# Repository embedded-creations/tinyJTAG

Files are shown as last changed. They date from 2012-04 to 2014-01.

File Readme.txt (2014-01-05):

tinyJTAG is a modification of the USBasp project to program via JTAG
instead of SPI or TPI, and to run on the ATtiny85.  

LICENSE
tinyJTAG is distributed under the terms and conditions of the GNU GPL version
2 (see "firmware/usbdrv/License.txt" for details).

CAUTIONS

Hardware:
All 6 IO pins of the ATtiny85 are used, including the reset pin.  The 
RSTDISBL fuse needs to be programmed to disable external reset funcionality
and enable use of the reset pin as IO.  After programming the fuse the part
can only be programmed through a high-voltage programmmer, or through the 
USBaspLoader-tiny85 boot loader.  The project is intended to be used in
conjunction with the USBaspLoader-tiny85 boot loader, and so doesn't include
an easy way to disable the external reset fuse in the makefile.  The 
USBaspLoader-tiny85 boot loader should be loaded on to the part first, tested
to make sure it was flashed properly, then the reset fuse can be disabled and 
the tinyJTAG firmware loaded through AVRDUDE.

Use:
If loading the the precompiled binary with bootloader, the bootloader will identify itself as a USBasp
programmer with an ATtiny85 target for five seconds before starting the 
tinyJTAG programmer, which will identify itself as a USBasp programmer.  
Wait for five seconds after connecting the tinyJTAG programmer to USB before
using AVRDUDE to connect to the JTAG target.  Be especially cautious when programming
ATtiny85 targets that you are connected to the tinyJTAG application and 
not the bootloader, as you could inadvertently erase the tinyJTAG application.

USE PRECOMPILED VERSION
Firmware:
Set the fuses and load USBaspLoader-tiny85 onto the tiny85 using your programmer of choice
- "make fuses" and "make flash" in USBaspLoader-tiny85\firmware directory
Verify that the boot loader was loaded correctly and that AVRDUDE can connect to it
- a signature read in AVRDUDE should show the ATtiny85 fuses
When you're sure you're ready, disable the external reset fuse on the tiny85
- see "CAUTIONS" in the USBaspLoader-tiny85 project
- "make disablereset" in USBaspLoader-tiny85\firmware directory
Load the tinyJTAG firmware
- "make flash" in tinyJTAG/firmware directory

There are no jumpers that need to be set for programming with an external programmer

BUILDING AND INSTALLING FROM SOURCE CODE

Firmware:
...

For more information on the tinyJTAG programmer, please visit the
following URL:

http://www.embedded-creations.com

(c) 2012 Louis Beaudoin

Below is the unmodified README file for USBasp:

=========================================================================

This is the README file for USBasp.

USBasp is a USB in-circuit programmer for Atmel AVR controllers. It simply
consists of an ATMega88 or an ATMega8 and a couple of passive components.
The programmer uses a firmware-only USB driver, no special USB controller
is needed.

Features:
- Works under multiple platforms. Linux, Mac OS X and Windows are tested.
- No special controllers or smd components are needed.
- Programming speed is up to 5kBytes/sec.
- SCK option to support targets with low clock speed (< 1,5MHz).
- Planned: serial interface to target (e.g. for debugging).

LICENSE

USBasp is distributed under the terms and conditions of the GNU GPL version
2 (see "firmware/usbdrv/License.txt" for details).

USBasp is built with V-USB driver by OBJECTIVE DEVELOPMENT GmbH. See
"firmware/usbdrv/" for further information.

LIMITATIONS

Hardware:
This package includes a circuit diagram. This circuit can only be used for
programming 5V target systems. For other systems a level converter is needed.

Firmware:
The firmware dosn't support USB Suspend Mode. A bidirectional serial
interface to slave exists in hardware but the firmware doesn't support it yet.

USE PRECOMPILED VERSION

Firmware:
Flash "bin/firmware/usbasp.atmega88.xxxx-xx-xx.hex" or
"bin/firmware/usbasp.atmega8.xxxx-xx-xx.hex" to the used controller with a
working programmer (e.g. with avrdude, uisp, ...). Set jumper J2 to activate
USBasp firmware update function.
You have to change the fuse bits for external crystal (see "make fuses").
# TARGET=atmega8    HFUSE=0xc9  LFUSE=0xef
# TARGET=atmega48   HFUSE=0xdd  LFUSE=0xff
# TARGET=atmega88   HFUSE=0xdd  LFUSE=0xff

Windows:
Start Windows and connect USBasp to the system. When Windows asks for a
driver, choose "bin/win-driver". On Win2k and WinXP systems, Windows will
warn that the driver is is not 'digitally signed'. Ignore this message and
continue with the installation.
Now you can run avrdude. Examples:
1. Enter terminal mode with an AT90S2313 connected to the programmer:
   avrdude -c usbasp -p at90s2313 -t
2. Write main.hex to the flash of an ATmega8:
   avrdude -c usbasp -p atmega8 -U flash:w:main.hex

Setting jumpers:
J1 Power target
   Supply target with 5V (USB voltage). Be careful with this option, the
   circuit isn't protected against short circuit!
J2 Jumper for firmware upgrade (not self-upgradable)
   Set this jumper for flashing the ATMega(4)8 of USBasp with another working
   programmer.
J3 SCK option
   If the target clock is lower than 1,5 MHz, you have to set this jumper.
   Then SCK is scaled down from 375 kHz to about 8 kHz.

BUILDING AND INSTALLING FROM SOURCE CODE

Firmware:
To compile the firmware
1. install the GNU toolchain for AVR microcontrollers (avr-gcc, avr-libc),
2. change directory to firmware/
3. run "make main.hex"
4. flash "main.hex" to the ATMega(4)8. E.g. with uisp or avrdude (check
the Makefile option "make flash"). To flash the firmware you have
to set jumper J2 and connect USBasp to a working programmer.
You have to change the fuse bits for external crystal, (check the Makefile
option "make fuses").

Software (avrdude):
AVRDUDE supports USBasp since version 5.2. 
1. install libusb: http://libusb.sourceforge.net/
2. get latest avrdude release: http://download.savannah.gnu.org/releases/avrdude/
3. cd avrdude-X.X.X
5. configure to your environment:
   ./bootstrap (I had to comment out the two if-blocks which verify the
                installed versions of autoconf and automake)
   ./configure
6. compile and install it:
   make 
   make install

Notes on Windows (Cygwin):
Download libusb-win32-device-bin-x.x.x.x.tar.gz from
http://libusb-win32.sourceforge.net/ and unpack it.
-> copy lib/gcc/libusb.a to lib-path
-> copy include/usb.h to include-path
cd avrdude
./configure LDFLAGS="-static" --enable-versioned-doc=no
make

Notes on Darwin/MacOS X:
after "./configure" I had to edit Makefile:
change "avrdude_CPPFLAGS" to "AM_CPPFLAGS"
(why is this needed only on mac? bug in configure.ac?)

Notes on Linux:
To use USBasp as non-root, you have to define some device rules. See
bin/linux-nonroot for an example.

FILES IN THE DISTRIBUTION

Readme.txt ...................... The file you are currently reading
firmware ........................ Source code of the controller firmware
firmware/usbdrv ................. AVR USB driver by Objective Development
firmware/usbdrv/License.txt ..... Public license for AVR USB driver and USBasp
circuit ......................... Circuit diagram in PDF and EAGLE format
bin ............................. Precompiled programs
bin/win-driver .................. Windows driver
bin/firmware .................... Precompiled firmware
bin/linux-nonroot ............... Linux device rule file

MORE INFORMATION

For more information on USBasp and it's components please visit the
following URLs:

USBasp .......................... http://www.fischl.de/usbasp/

Firmware-only V-USB driver ...... http://www.obdev.at/products/vusb/
avrdude ......................... http://www.nongnu.org/avrdude/
libusb .......................... http://libusb.sourceforge.net/
libusb-win32 .................... http://libusb-win32.sourceforge.net/

2011-05-28 Thomas Fischl <tfischl@gmx.de>
http://www.fischl.de

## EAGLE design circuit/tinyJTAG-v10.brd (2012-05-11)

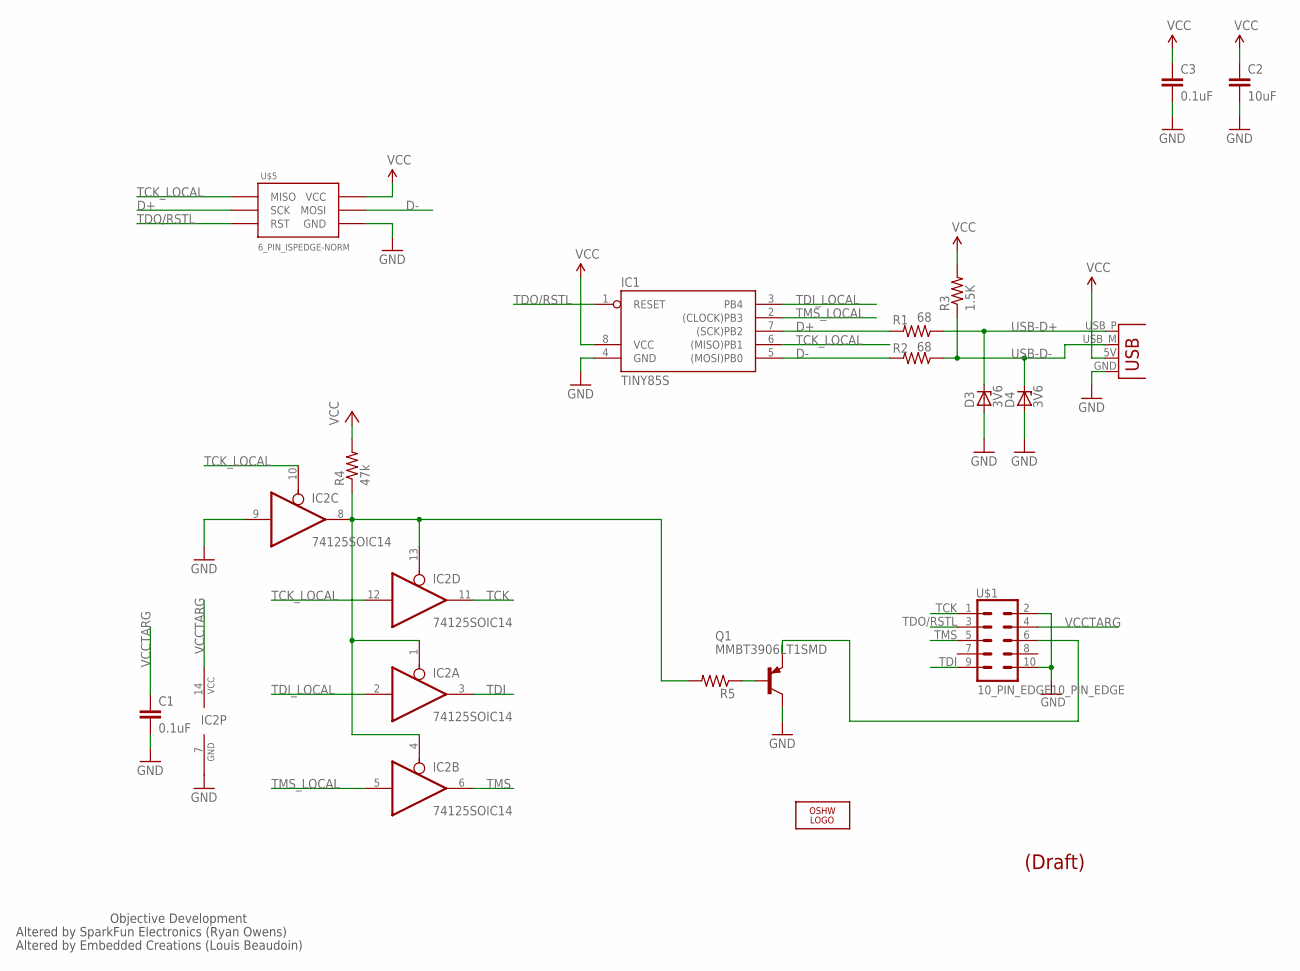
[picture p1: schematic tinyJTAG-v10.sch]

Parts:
C1, C3: 0.1uF; 0603-CAP
C2: 10uF; C0805
D3, D4: 3V6; DIODE_SOD323-W
IC1: TINY85S; SOIC8
IC2: 74125SOIC14; SO14
LOGO1: OSHW_LOGO_FILLX0150-NT; OSHW_FILLX150_NOTEXT
Q1: MMBT3906LT1SMD; SOT23-BEC
R1, R2: 68; 0603-RES
R3: 1.5K; 0603-RES
R4: 47k; 0603-RES
R5: RESISTOR0603-RES; 0603-RES
U$1: 10_PIN_EDGE10_PIN_EDGE; 10_PIN_EDGE
U$5: 6_PIN_ISPEDGE-NORM; 6_PIN_EDGE
X1: USBPCB; USB-A-PCB

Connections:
D+: IC1.7 ((SCK)PB2), R1.2, U$5.3 (SCK)
D-: IC1.5 ((MOSI)PB0), R2.2, U$5.4 (MOSI)
GND: C1.2, C2.2, C3.2, D3.A, D4.A, IC1.4 (GND), IC2.7 (GND), IC2.9 (I), Q1.C, U$1.2, U$1.10, U$5.6 (GND), X1.GND
unnamed: IC2.1 (OE), IC2.4 (OE), IC2.8 (O), IC2.13 (OE), R4.1, R5.2
unnamed: Q1.E, U$1.6
unnamed: Q1.B, R5.1
TCK: IC2.11 (O), U$1.1
TCK_LOCAL: IC1.6 ((MISO)PB1), IC2.10 (OE), IC2.12 (I), U$5.1 (MISO)
TDI: IC2.3 (O), U$1.9
TDI_LOCAL: IC1.3 (PB4), IC2.2 (I)
TDO/RSTL: IC1.1 (RESET), U$1.3, U$5.5 (RST)
TMS: IC2.6 (O), U$1.5
TMS_LOCAL: IC1.2 ((CLOCK)PB3), IC2.5 (I)
USB-D+: D3.C, R1.1, X1.USB_P (D+)
USB-D-: D4.C, R2.1, R3.1, X1.USB_M (D-)
VCC: C2.1, C3.1, IC1.8 (VCC), R3.2, R4.2, U$5.2 (VCC), X1.5V (VBUS)
VCCTARG: C1.1, IC2.14 (VCC), U$1.4

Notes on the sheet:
Objective Development
Altered by SparkFun Electronics (Ryan Owens)
Altered by Embedded Creations (Louis Beaudoin)
(Draft)

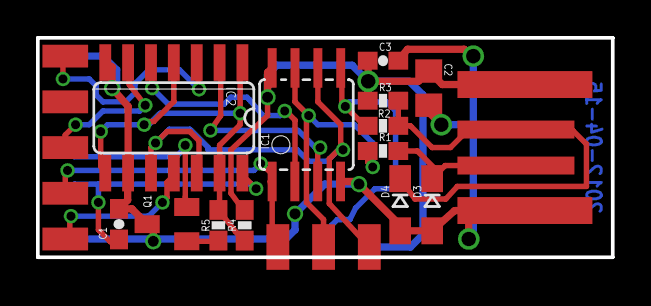
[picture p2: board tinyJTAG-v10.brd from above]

Board: 2 copper layers, 31.9 x 12.2 mm, 17 parts (1 on the bottom side), 17 nets.

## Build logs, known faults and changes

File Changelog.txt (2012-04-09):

tinyJTAG.2011-04-XX (v1.5)
-----------------------------
- by Louis Beaudoin (Embedded-Creations.com)
- added JTAG programming support in place of ISP and TPI
- added support for running on ATtiny85 with internal oscillator

=================================================================

usbasp.2011-05-28 (v1.4)
------------------------
- added TPI support for ATTiny4/5/6/10 (by Slawomir Fraś)
- added support for controllers with flash >128kb (by Slawomir Fraś)
- fixed resync after program enable signal to pulse RST (based on patch by Marco S)
- updated usb driver to V-USB Release 2010-07-15

usbasp.2009-02-28 (v1.3)
------------------------
- added support for software control of ISP speed (based on patch by Jurgis Brigmanis)
- included new AVRUSB driver version (Release 2008-11-26)
- added libusb 0.1.12.1 windows drivers (needed for WinAVR version 20080512 or greater)

usbasp.2007-10-23 (v1.2)
------------------------
- red LED turns on before connecting to target device: this signal can be used to control external tri-state buffers (by Pawel Szramowski)

usbasp.2007-07-23
-----------------
- changed licence to GNU GPL v2
- included new AVRUSB driver version (Release 2007-07-07); AVRUSB licence was changed to GNU GPL v2
- fixed long addressing for Mega128 (by BoskiDialer)

usbasp.2006-12-29
-----------------
- fixed returnvalue in usbWriteFunction (by Jeroen Koeter)
- changed clock.h: adaptation for newer MCUs like ATMega48 (by Hanns-Konrad Unger)
- improved Makefile to select target (by Hanns-Konrad Unger)
- circuit diagram: added zener diodes to USB data lines 

usbasp.2006-09-16
-----------------
- add usb reset on startup
- included new AVRUSB driver version (Release 2006-07-18)
- changed VID and PID to OBDEV's shared IDs to meet new licence conditions
- removed avrdude patch from this package. USBasp is supported in latest avrdude CVS version 

usbasp.2005-11-14
-----------------
- fixed blocksize restriction (programming the Mega128 now works) 
  by Thomas Pfeifer (TP)
- update patch for avrdude-5.0

usbasp.2005-07-03
-----------------
- set USB_CFG_SAMPLE_EXACT in usbconfig.h to reduce problems with long cables
- corrected vendor string
- added notes on setting fuse bits

usbasp.2005-04-21
-----------------
- first public version

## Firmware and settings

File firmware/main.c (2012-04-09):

/*
 * USBasp - USB in-circuit programmer for Atmel AVR controllers
 *
 * Thomas Fischl <tfischl@gmx.de>
 *
 * License........: GNU GPL v2 (see Readme.txt)
 * Target.........: ATMega8 at 12 MHz
 * Creation Date..: 2005-02-20
 * Last change....: 2009-02-28
 *
 * PC2 SCK speed option.
 * GND  -> slow (8khz SCK),
 * open -> software set speed (default is 375kHz SCK)
 */

#include <avr/io.h>
#include <avr/interrupt.h>
#include <avr/pgmspace.h>
#include <avr/wdt.h>

#include "usbasp.h"
#include "usbdrv.h"
#include "isp.h"
#include "clock.h"
#include <util/delay.h>
#include "tpi.h"
#include "tpi_defs.h"

#include "jtag.h"
#include "hardware.h"

//#define UART_DEBUG

#ifdef UART_DEBUG
#include "buffuart.h"
#endif


static uchar replyBuffer[8];

static uchar prog_state = PROG_STATE_IDLE;
static uchar prog_sck = USBASP_ISP_SCK_AUTO;

static uchar prog_address_newmode = 0;
static unsigned long prog_address;
static unsigned int prog_nbytes = 0;
static unsigned int prog_pagesize;
static uchar prog_blockflags;
static uchar prog_pagecounter;

unsigned int flashpagesize;

uchar usbFunctionSetup(uchar data[8]) {

	uchar len = 0;

#ifdef UART_DEBUG
	TransmitHex(data[1]);
#endif
	
	if (data[1] == USBASP_FUNC_CONNECT) {

#if 0
	    /* set SCK speed */
		if ((PINC & (1 << PC2)) == 0) {
			ispSetSCKOption(USBASP_ISP_SCK_8);
		} else {
			ispSetSCKOption(prog_sck);
		}
#endif

		/* set compatibility mode of address delivering */
		prog_address_newmode = 0;

		ledRedOn();
		ispConnect();

	} else if (data[1] == USBASP_FUNC_DISCONNECT) {
		ispDisconnect();
		ledRedOff();

	} else if (data[1] == USBASP_FUNC_TRANSMIT) {
		// debug - print out contents of message
#ifdef UART_DEBUG
		TransmitHex(data[2]);
		TransmitHex(data[3]);
		TransmitHex(data[4]);
		TransmitHex(data[5]);
#endif
		replyBuffer[0] = 0;
		replyBuffer[1] = 0;
		replyBuffer[2] = 0;
		replyBuffer[3] = interpretSPICommand(&data[2]);
		len = 4;
		
	} else if (data[1] == USBASP_FUNC_READFLASH) {

		if (!prog_address_newmode)
			prog_address = (data[3] << 8) | data[2];

		prog_nbytes = (data[7] << 8) | data[6];
		prog_state = PROG_STATE_READFLASH;
		len = 0xff; /* multiple in */

	} else if (data[1] == USBASP_FUNC_READEEPROM) {

		if (!prog_address_newmode)
			prog_address = (data[3] << 8) | data[2];

		prog_nbytes = (data[7] << 8) | data[6];
		prog_state = PROG_STATE_READEEPROM;
		len = 0xff; /* multiple in */

	} else if (data[1] == USBASP_FUNC_ENABLEPROG) {
		replyBuffer[0] = ispEnterProgrammingMode();
		len = 1;

	} else if (data[1] == USBASP_FUNC_WRITEFLASH) {

		if (!prog_address_newmode)
			prog_address = (data[3] << 8) | data[2];

		prog_pagesize = data[4];
		prog_blockflags = data[5] & 0x0F;
		prog_pagesize += (((unsigned int) data[5] & 0xF0) << 4);
		if (prog_blockflags & PROG_BLOCKFLAG_FIRST) {
			prog_pagecounter = prog_pagesize;
		}
		prog_nbytes = (data[7] << 8) | data[6];
		prog_state = PROG_STATE_WRITEFLASH;
		len = 0xff; /* multiple out */

	} else if (data[1] == USBASP_FUNC_WRITEEEPROM) {

		if (!prog_address_newmode)
			prog_address = (data[3] << 8) | data[2];

		prog_pagesize = 0;
		prog_blockflags = 0;
		prog_nbytes = (data[7] << 8) | data[6];
		prog_state = PROG_STATE_WRITEEEPROM;
		len = 0xff; /* multiple out */

	} else if (data[1] == USBASP_FUNC_SETLONGADDRESS) {

		/* set new mode of address delivering (ignore address delivered in commands) */
		prog_address_newmode = 1;
		/* set new address */
		prog_address = *((unsigned long*) &data[2]);

	} else if (data[1] == USBASP_FUNC_SETISPSCK) {

		/* set sck option */
		prog_sck = data[2];
		replyBuffer[0] = 0;
		len = 1;

#if 0
		} else if (data[1] == USBASP_FUNC_TPI_CONNECT) {
		tpi_dly_cnt = data[2] | (data[3] << 8);

		/* RST high */
		ISP_OUT |= (1 << ISP_RST);
		ISP_DDR |= (1 << ISP_RST);

		clockWait(3);

		/* RST low */
		ISP_OUT &= ~(1 << ISP_RST);
		ledRedOn();

		clockWait(16);
		tpi_init();
	
	} else if (data[1] == USBASP_FUNC_TPI_DISCONNECT) {

		tpi_send_byte(TPI_OP_SSTCS(TPISR));
		tpi_send_byte(0);

		clockWait(10);

		/* pulse RST */
		ISP_OUT |= (1 << ISP_RST);
		clockWait(5);
		ISP_OUT &= ~(1 << ISP_RST);
		clockWait(5);

		/* set all ISP pins inputs */
		ISP_DDR &= ~((1 << ISP_RST) | (1 << ISP_SCK) | (1 << ISP_MOSI));
		/* switch pullups off */
		ISP_OUT &= ~((1 << ISP_RST) | (1 << ISP_SCK) | (1 << ISP_MOSI));

		ledRedOff();
	
	} else if (data[1] == USBASP_FUNC_TPI_RAWREAD) {
		replyBuffer[0] = tpi_recv_byte();
		len = 1;
	
	} else if (data[1] == USBASP_FUNC_TPI_RAWWRITE) {
		tpi_send_byte(data[2]);
	
	} else if (data[1] == USBASP_FUNC_TPI_READBLOCK) {
		prog_address = (data[3] << 8) | data[2];
		prog_nbytes = (data[7] << 8) | data[6];
		prog_state = PROG_STATE_TPI_READ;
		len = 0xff; /* multiple in */
	
	} else if (data[1] == USBASP_FUNC_TPI_WRITEBLOCK) {
		prog_address = (data[3] << 8) | data[2];
		prog_nbytes = (data[7] << 8) | data[6];
		prog_state = PROG_STATE_TPI_WRITE;
		len = 0xff; /* multiple out */
#endif
	} else if (data[1] == USBASP_FUNC_GETCAPABILITIES) {
		replyBuffer[0] = USBASP_CAP_0_TPI;
		replyBuffer[1] = 0;
		replyBuffer[2] = 0;
		replyBuffer[3] = 0;
		len = 4;
	}

	usbMsgPtr = replyBuffer;

#ifdef UART_DEBUG
	TransmitString("\r\n");
#endif

	return len;
}

uchar usbFunctionRead(uchar *data, uchar len) {

	/* check if programmer is in correct read state */
	if ((prog_state != PROG_STATE_READFLASH) && (prog_state
			!= PROG_STATE_READEEPROM) && (prog_state != PROG_STATE_TPI_READ)) {
		return 0xff;
	}

    if (prog_state == PROG_STATE_READFLASH) {
        AVRJTAGReadFlash(data, prog_address/2, len/2);
    } else {
        AVRJTAGReadEEPROM(data, prog_address, len);
    }

    prog_address += len;

	/* last packet? */
	if (len < 8) {
		prog_state = PROG_STATE_IDLE;
	}

	return len;
}

uchar usbFunctionWrite(uchar *data, uchar len) {

	uchar retVal = 0;
	uchar i;

	/* check if programmer is in correct write state */
	if ((prog_state != PROG_STATE_WRITEFLASH) && (prog_state
			!= PROG_STATE_WRITEEEPROM) && (prog_state != PROG_STATE_TPI_WRITE)) {
		return 0xff;
	}

#if 0
	if (prog_state == PROG_STATE_TPI_WRITE)
	{
		tpi_write_block(prog_address, data, len);
		prog_address += len;
		prog_nbytes -= len;
		if(prog_nbytes <= 0)
		{
			prog_state = PROG_STATE_IDLE;
			return 1;
		}
		return 0;
	}
#endif

#if 0
#ifdef UART_DEBUG
	if (prog_state == PROG_STATE_WRITEFLASH)
        TransmitString("WRFL\r\n");

    TransmitString("len:");
    TransmitHex(len);
    TransmitString("\r\n");

    TransmitString("ctr:");
    TransmitHex(prog_pagecounter/256);
    TransmitHex(prog_pagecounter);
    TransmitString("\r\n");

    TransmitString("size:");
    TransmitHex(prog_pagesize/256);
    TransmitHex(prog_pagesize);
    TransmitString("\r\n");

    TransmitString("adx:");
    TransmitHex(prog_address/256/256);
    TransmitHex(prog_address/256);
    TransmitHex(prog_address);
    TransmitString("\r\n");
#endif

#endif

    flashpagesize = prog_pagesize;

    for (i = 0; i < len; i++) {

		if (prog_state == PROG_STATE_WRITEFLASH) {
			/* Flash */

			if (prog_pagesize == 0) {
				/* not paged */
#ifdef UART_DEBUG
			    TransmitString("NP write not supported");
#endif
			    return 0xff;
			} else {
				/* paged */
                // load one word into the flash buffer
			    AVRJTAGLoadFlashPage(data + i, prog_address/2, 1);
			    i++;

				prog_pagecounter--;
				prog_pagecounter--;

				if (prog_pagecounter == 0) {
				    AVRJTAGWriteFlashPage(prog_address/2);
					prog_pagecounter = prog_pagesize;
				}
			}

		} else {
			/* EEPROM */
		    AVRJTAGProgramEEPROMByte(data[i], prog_address);
		}

        if (prog_state == PROG_STATE_WRITEFLASH) {
            prog_nbytes-=2;
        } else {
            prog_nbytes--;
        }

		if (prog_nbytes == 0) {
			if ((prog_blockflags & PROG_BLOCKFLAG_LAST) && (prog_pagecounter
					!= prog_pagesize)) {

				/* last block and page flush pending, so flush it now */
		        if (prog_state == PROG_STATE_WRITEFLASH) {
		            AVRJTAGWriteFlashPage(prog_address/2);
		        }

		        // No need to flush EEPROM
            }

            prog_state = PROG_STATE_IDLE;
			retVal = 1; // Need to return 1 when no more data is to be received
		}

        if (prog_state == PROG_STATE_WRITEFLASH) {
            prog_address += 2;
        } else {
            prog_address++;
        }
	}

	return retVal;
}

int main(void) {
	uchar i, j;

	/* no pullups on USB and ISP pins */
	//PORTD = 0;
	//PORTB = 0;
	/* all outputs except PD2 = INT0 */
	/// LB - different pins on STK500 board
	//DDRD = ~(1 << 2);
	// make JTAG pins inputs with pullups	
	SET_JTAG_PULLUPS();

	/* output SE0 for USB reset */
	/// LB - different pins on STK500 board
	//DDRB = ~0;
	j = 0;
	/* USB Reset by device only required on Watchdog Reset */
	while (--j) {
		i = 0;
		/* delay >10ms for USB reset */
		while (--i)
			;
	}
	/* all USB and ISP pins inputs */
	//DDRB = 0;

	/// LB - LED pins are different from usbasp to sp duo - conflict: SP duo uses these for JTAG
	/* all inputs except PC0, PC1 */
	//DDRC = 0x03;
	//PORTC = 0xfe;
	SET_LED_OUTPUT();
	LED_OFF();

	/* init timer */
	clockInit();

	
#ifdef UART_DEBUG
    // init debug uart
    setupUART();

    TransmitString("\r\n\n***\r\nstarting up\r\n");
#endif
	
	// USB Re-Enumeration
	usbDeviceDisconnect();
	while(--i){         // fake USB disconnect for > 250 ms
	    wdt_reset();    // if watchdog is active, reset it
	    _delay_ms(1);   // library call -- has limited range
	}
	usbDeviceConnect();

	/* main event loop */
	usbInit();
	sei();
	for (;;) {
		usbPoll();
	}
	return 0;
}

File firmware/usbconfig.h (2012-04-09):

/* Name: usbconfig.h
 * Project: AVR USB driver
 * Author: Christian Starkjohann, Thomas Fischl
 * Creation Date: 2005-04-01
 * Tabsize: 4
 * Copyright: (c) 2005 by OBJECTIVE DEVELOPMENT Software GmbH
 * License: GNU GPL v2 (see License.txt) or proprietary (CommercialLicense.txt)
 */

#ifndef __usbconfig_h_included__
#define __usbconfig_h_included__

/*
General Description:
This file contains parts of the USB driver which can be configured and can or
must be adapted to your hardware.

Please note that the usbdrv contains a usbconfig-prototype.h file now. We
recommend that you use that file as a template because it will always list
the newest features and options.
*/

/* ---------------------------- Hardware Config ---------------------------- */

#define USB_CFG_IOPORTNAME      B
/* This is the port where the USB bus is connected. When you configure it to
 * "B", the registers PORTB, PINB and DDRB will be used.
 */
#define USB_CFG_DMINUS_BIT      0
/* This is the bit number in USB_CFG_IOPORT where the USB D- line is connected.
 * This may be any bit in the port.
 */
#define USB_CFG_DPLUS_BIT       2
/* This is the bit number in USB_CFG_IOPORT where the USB D+ line is connected.
 * This may be any bit in the port. Please note that D+ must also be connected
 * to interrupt pin INT0!
 */
#define USB_CFG_CLOCK_KHZ F_CPU/1000
/* Clock rate of the AVR in MHz. Legal values are 12000, 16000 or 16500.
 * The 16.5 MHz version of the code requires no crystal, it tolerates +/- 1%
 * deviation from the nominal frequency. All other rates require a precision
 * of 2000 ppm and thus a crystal!
 * Default if not specified: 12 MHz
 */

/* ----------------------- Optional Hardware Config ------------------------ */

/* #define USB_CFG_PULLUP_IOPORTNAME   D */
/* If you connect the 1.5k pullup resistor from D- to a port pin instead of
 * V+, you can connect and disconnect the device from firmware by calling
 * the macros usbDeviceConnect() and usbDeviceDisconnect() (see usbdrv.h).
 * This constant defines the port on which the pullup resistor is connected.
 */
/* #define USB_CFG_PULLUP_BIT          4 */
/* This constant defines the bit number in USB_CFG_PULLUP_IOPORT (defined
 * above) where the 1.5k pullup resistor is connected. See description
 * above for details.
 */

/* --------------------------- Functional Range ---------------------------- */

#define USB_CFG_HAVE_INTRIN_ENDPOINT    0
/* Define this to 1 if you want to compile a version with two endpoints: The
 * default control endpoint 0 and an interrupt-in endpoint 1.
 */
#define USB_CFG_HAVE_INTRIN_ENDPOINT3   0
/* Define this to 1 if you want to compile a version with three endpoints: The
 * default control endpoint 0, an interrupt-in endpoint 1 and an interrupt-in
 * endpoint 3. You must also enable endpoint 1 above.
 */
#define USB_CFG_IMPLEMENT_HALT          0
/* Define this to 1 if you also want to implement the ENDPOINT_HALT feature
 * for endpoint 1 (interrupt endpoint). Although you may not need this feature,
 * it is required by the standard. We have made it a config option because it
 * bloats the code considerably.
 */
#define USB_CFG_INTR_POLL_INTERVAL      10
/* If you compile a version with endpoint 1 (interrupt-in), this is the poll
 * interval. The value is in milliseconds and must not be less than 10 ms for
 * low speed devices.
 */
#define USB_CFG_IS_SELF_POWERED         0
/* Define this to 1 if the device has its own power supply. Set it to 0 if the
 * device is powered from the USB bus.
 */
#define USB_CFG_MAX_BUS_POWER           50
/* Set this variable to the maximum USB bus power consumption of your device.
 * The value is in milliamperes. [It will be divided by two since USB
 * communicates power requirements in units of 2 mA.]
 */
#define USB_CFG_IMPLEMENT_FN_WRITE      1
/* Set this to 1 if you want usbFunctionWrite() to be called for control-out
 * transfers. Set it to 0 if you don't need it and want to save a couple of
 * bytes.
 */
#define USB_CFG_IMPLEMENT_FN_READ       1
/* Set this to 1 if you need to send control replies which are generated
 * "on the fly" when usbFunctionRead() is called. If you only want to send
 * data from a static buffer, set it to 0 and return the data from
 * usbFunctionSetup(). This saves a couple of bytes.
 */
#define USB_CFG_IMPLEMENT_FN_WRITEOUT   0
/* Define this to 1 if you want to use interrupt-out (or bulk out) endpoint 1.
 * You must implement the function usbFunctionWriteOut() which receives all
 * interrupt/bulk data sent to endpoint 1.
 */
#define USB_CFG_HAVE_FLOWCONTROL        0
/* Define this to 1 if you want flowcontrol over USB data. See the definition
 * of the macros usbDisableAllRequests() and usbEnableAllRequests() in
 * usbdrv.h.
 */

/* -------------------------- Device Description --------------------------- */
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

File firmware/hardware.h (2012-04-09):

#define SPBETA1 1
#define SPV10   2
#define TINY85	3
#define HARDWAREDEF TINY85

#if HARDWAREDEF == SPBETA1

#define RESETPIN 0
#define RESETDDR DDRB
#define SPIDDR  DDRB
#define SPIPORT PORTB
#define SCKPIN  5
#define MOSIPIN 3
#define MISOPIN 4
#define SSPIN   2

#define JTAG_PORT   PORTC
#define JTAG_DDR    DDRC
#define JTAG_PINS   PINC
#define JTAG_TCK    0
#define JTAG_TMS    2
#define JTAG_TDI    3
#define JTAG_TDO    1

#define SET_JTAG_TCK() asm volatile("sbi 0x15, 0")
#define SET_JTAG_TMS() asm volatile("sbi 0x15, 2")
#define SET_JTAG_TDI() asm volatile("sbi 0x15, 3")
#define CLEAR_JTAG_TCK() asm volatile("cbi 0x15, 0")
#define CLEAR_JTAG_TMS() asm volatile("cbi 0x15, 2")
#define CLEAR_JTAG_TDI() asm volatile("cbi 0x15, 3")
#endif


#if HARDWAREDEF == SPV10
#define RESETPIN 5
#define RESETDDR DDRC
#define SPIDDR  DDRB
#define SPIPORT PORTB
#define SCKPIN  5
#define MOSIPIN 3
#define MISOPIN 4
#define SSPIN   2

#define LEDTARGPIN 4
#define LEDTARGDDR DDRC

#define JTAG_PORT   PORTC
#define JTAG_DDR    DDRC
#define JTAG_PINS   PINC
#define JTAG_TCK    1
#define JTAG_TMS    2
#define JTAG_TDI    0
#define JTAG_TDO    3

#define SET_JTAG_TCK()      (JTAG_PORT |= _BV(JTAG_TCK))
#define SET_JTAG_TMS()      (JTAG_PORT |= _BV(JTAG_TMS))
#define SET_JTAG_TDI()      (JTAG_PORT |= _BV(JTAG_TDI))
#define CLEAR_JTAG_TCK()    (JTAG_PORT &= ~_BV(JTAG_TCK))
#define CLEAR_JTAG_TMS()    (JTAG_PORT &= ~_BV(JTAG_TMS))
#define CLEAR_JTAG_TDI()    (JTAG_PORT &= ~_BV(JTAG_TDI))

#define CTSPORT PORTD
#define CTSDDR  DDRD
#define CTSPIN  4

#define RELEASE_LEDTARG() LEDTARGDDR &= ~_BV(LEDTARGPIN)
#define DRIVE_LEDTARG() LEDTARGDDR |= _BV(LEDTARGPIN)

#define SET_LED_OUTPUT()    
#define LED_OFF()   

/* macros for gpio functions */
#define ledRedOn()    
#define ledRedOff()   
#define ledGreenOn()  
#define ledGreenOff() 

#define READ_JTAG_TDO()         bit_is_set(JTAG_PINS, JTAG_TDO)

#define SET_JTAG_OUTPUT()       (JTAG_DDR |= _BV(JTAG_TCK) | _BV(JTAG_TMS) | _BV(JTAG_TDI))

#define CLEAR_JTAG_OUTPUT()     (JTAG_DDR &= ~(_BV(JTAG_TCK) | _BV(JTAG_TMS) | _BV(JTAG_TDI)))

#endif


#if HARDWAREDEF == TINY85


#define LEDTARGPIN 4
#define LEDTARGDDR DDRC

#define JTAG_PORT   PORTB
#define JTAG_DDR    DDRB
#define JTAG_PINS   PINB
#define JTAG_TCK    1
#define JTAG_TMS    3
#define JTAG_TDI    4
#define JTAG_TDO    5

#define SET_JTAG_TCK()      (JTAG_PORT |= _BV(JTAG_TCK))
#define SET_JTAG_TMS()      (JTAG_PORT |= _BV(JTAG_TMS))
#define SET_JTAG_TDI()      (JTAG_PORT |= _BV(JTAG_TDI))
#define CLEAR_JTAG_TCK()    (JTAG_PORT &= ~_BV(JTAG_TCK))
#define CLEAR_JTAG_TMS()    (JTAG_PORT &= ~_BV(JTAG_TMS))
#define CLEAR_JTAG_TDI()    (JTAG_PORT &= ~_BV(JTAG_TDI))

#define CTSPORT PORTD
#define CTSDDR  DDRD
#define CTSPIN  4

#define RELEASE_LEDTARG()   (LEDTARGDDR &= ~_BV(LEDTARGPIN))
#define DRIVE_LEDTARG()     (LEDTARGDDR |= _BV(LEDTARGPIN))

#define SET_LED_OUTPUT()
#define LED_OFF()

/* macros for gpio functions */
#define ledRedOn()
#define ledRedOff()
#define ledGreenOn()
#define ledGreenOff()

#define READ_JTAG_TDO()         bit_is_set(JTAG_PINS, JTAG_TDO)

#define SET_JTAG_OUTPUT()       (JTAG_DDR |= _BV(JTAG_TCK) | _BV(JTAG_TMS) | _BV(JTAG_TDI))

#define CLEAR_JTAG_OUTPUT()     (JTAG_DDR &= ~(_BV(JTAG_TCK) | _BV(JTAG_TMS) | _BV(JTAG_TDI)))
#define SET_JTAG_PULLUPS()      (JTAG_PORT |= _BV(JTAG_TCK) | _BV(JTAG_TMS) | _BV(JTAG_TDI) )


#endif


#ifndef RELEASE_RESET
#define RELEASE_RESET() //RESETDDR &= ~_BV(RESETPIN);
#endif
#ifndef DRIVE_RESET
#define DRIVE_RESET() //RESETDDR |= _BV(RESETPIN)
#endif

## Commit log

2012-04-09 added CC info back
    [tinyJTAG-v10.brd, tinyJTAG-v10.sch]
2012-04-14 added "draft" to title
    [tinyJTAG-v10.sch]
2012-05-11 Version sent for manufacturing initial prototypes
    [tinyJTAG-v10.brd, tinyJTAG-v10.sch]
2012-05-11 cleaned up CC license and made visible
    [tinyJTAG-v10.brd]

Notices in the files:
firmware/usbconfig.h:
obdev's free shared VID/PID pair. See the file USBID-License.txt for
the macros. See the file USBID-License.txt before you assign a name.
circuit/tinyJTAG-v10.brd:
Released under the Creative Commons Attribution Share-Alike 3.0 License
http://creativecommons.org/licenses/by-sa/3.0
